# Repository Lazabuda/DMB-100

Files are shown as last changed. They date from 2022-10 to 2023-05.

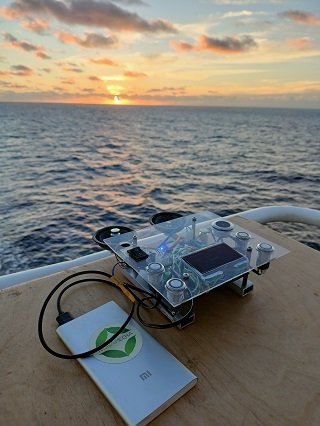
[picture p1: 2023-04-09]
Additional_files/DMB-100.jpg

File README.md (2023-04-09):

# DMB-100
Digital Marine Balances - 100 (max. weight = 100g)

! ! ! ! !
Before PCB mounting:
R43, R44, C24 - do not install (by default). Install if you want to use B channel of ADC HX711.
R25, R33 - do not install if you use internal on-chip oscillator (by default).
R29, R39 - do not install, data rate control, installed R31, R40 means 0: 10Hz (by default); installed R29, R39 means 1: 80Hz.
R20, R23 - do not install if you use internal pull-up's for EPS32 GPIO2 and GPIO4

Something about RTC. You can use many different RTC's in SOIC-8 case and pin-to-pin compatible (if you need time and date on the display). I tried 2 types, one with two domains of power supply (battery and Vcc) and one only with Vcc (it is much cheaper). So, if you use second type with one domain, for example PCF8563, please do steps:
R1 - install 0 Ohm resistor if you use external power supply for RTC (after turning off the device real clock timer progress will be lost). I use this option for first tests. In this case, R2 - do not install.
R2 - install 0 Ohm resistor if you use 2032 battery for RTC (after turning off the device real clock timer progress will be saved). In this case, R1 - do not install.
R5 - not install. This resistor needs to be installed if you use RTC like M41T81

Shortly:

If you use RTC with two power supply domains, like M41T81:
R5, R1 - install 0 Ohm resistors, R2 - do not install

If you use RTC with one power supply domain, like PCF8563:
R2 - install 0 Ohm resistors, R5, R1 - do not install

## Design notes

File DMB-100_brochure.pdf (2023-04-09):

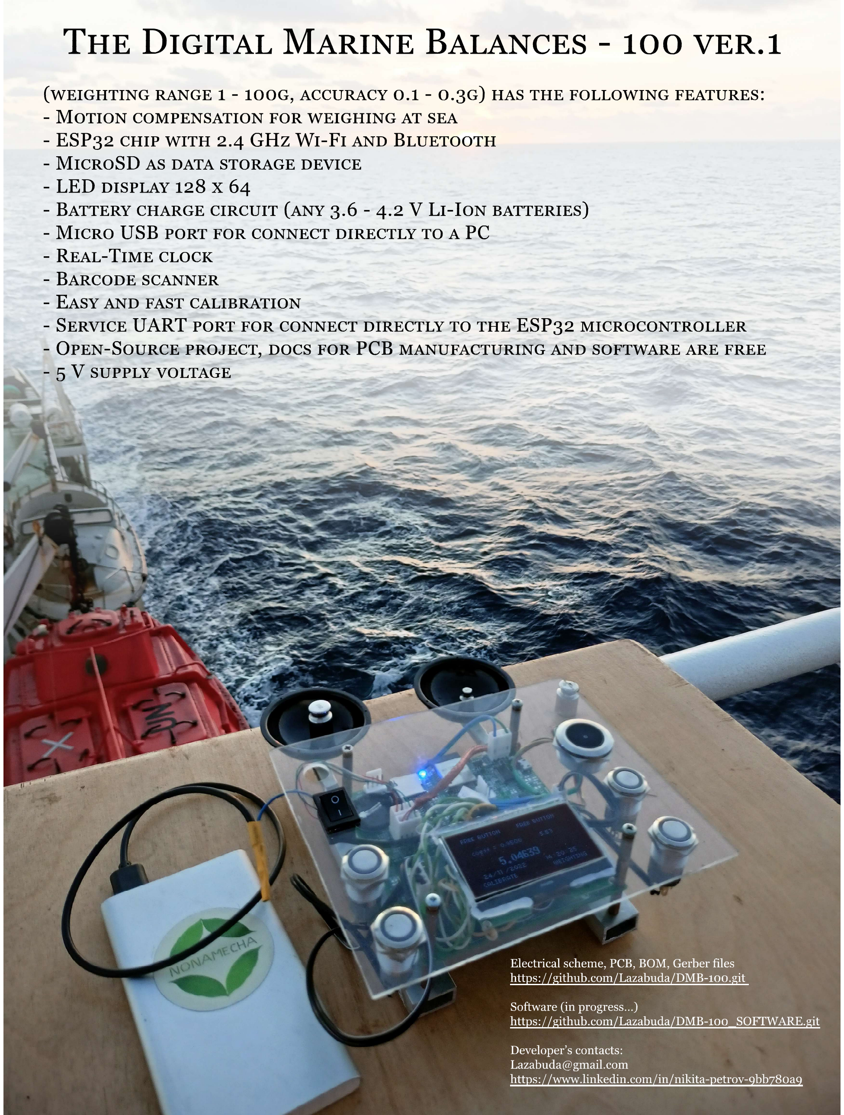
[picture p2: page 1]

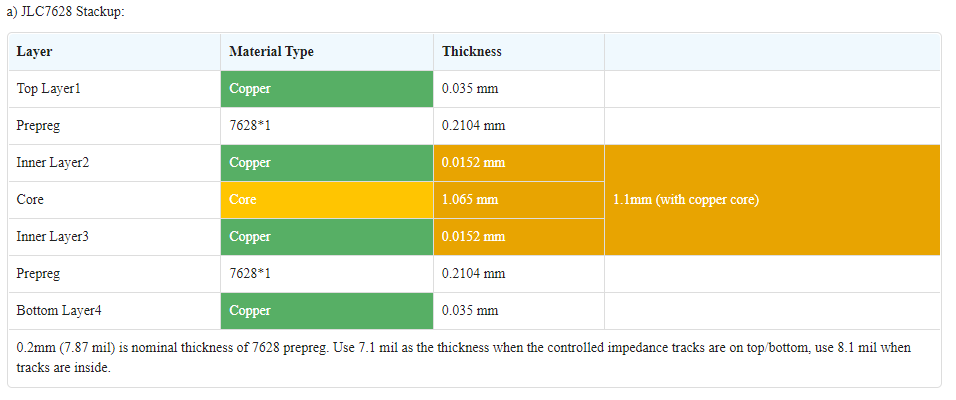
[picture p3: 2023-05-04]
Additional_files/Stackup.png

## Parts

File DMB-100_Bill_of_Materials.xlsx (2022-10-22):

Bill of Material Report (Condensed)
Part | COMP_DEVICE_TYPE | COMP_VALUE | QUANTITY | REFDES | Link
LED 1608 | LED_1608_1608_SMT_LED_LED_1608 | LED_1608 | 5 | VD1;VD2;VD7;VD8;VD10 | https://aliexpress.ru/item/1005003327360045.html?sku_id=12000025230762027
Battery Holder CR2032 | 2032_HOLDER_BAT_CH224_CR2032_2032_HOLDER | 2032_Holder | 1 | BAT1 | https://aliexpress.ru/item/4001240194584.html?sku_id=10000015424733532
Button 3x4x2.5 | BUTTON_4X3_BUTTON_3X4X2_5_BUTTON_4X3 | Button_4x3 | 2 | SW1;SW2 | https://aliexpress.ru/item/4001125532910.html?sku_id=10000014628669783
Button 6x6 | BUTTON_6X6_BUTTON_6X6_BUTTON_6X6 | Button_6x6 | 4 | SW3;SW4;SW5;SW6 | https://aliexpress.ru/item/32725582078.html?sku_id=61197879130
Capacitor 0603 | C_0603_CAP_0603_0.1 UF | 0.1 uF | 22 | C1;C2;C3;C4;C5;C6;C7;C9;C10;C11;C12;C13;C15;C17;C18;C20;C22;C23;C24;C25;C32;C33 | https://aliexpress.ru/item/32966526545.html?sku_id=66569661089
Capacitor 0805 | C_1_CAP_0805_10 UF | 10 uF | 11 | C8;C14;C16;C19;C21;C26;C27;C28;C29;C30;C31 | https://aliexpress.ru/item/32964553793.html
Capacitor 0805 | L_0805_CAP_0805_40 OHM | 40 Ohm | 1 | L1
FUSE 1206 | FUSE_1206_CAP_1206_FUSE_1206 | 500 mA | 2 | FU1;FU2 | https://aliexpress.ru/item/32901034711.html?sku_id=66684643012
Inductance CD54 | CD54_CD54_2.2 UH | 2.2 uH | 1 | L2 | https://aliexpress.ru/item/32886534770.html?sku_id=65669741576
Crystal 32.768 kHz | CRYSTAL_CRYSTAL_CYLINDER_2X6_32.768 KHZ | 32.768 kHz | 1 | Q1 | https://aliexpress.ru/item/4000124720113.html?sku_id=10000000352024848
Diode Shottky | DIODE_SHOTTKY_DIODE_DO-214AC_SS34 | SS34 | 1 | VD6 | https://aliexpress.ru/item/1005002002410774.html?sku_id=12000018375188551
TVS Diode | TVS_DIODE_SC-79_SOD523_DIODE_SOD_523_CESD3V3D5 | CESD3V3D5 | 4 | VD4;VD5;VD11;VD12 | https://aliexpress.ru/item/1005003621698282.html
TVS Diode | TVS_DIODE_SC-79_SOD523_DIODE_SOD_523_CESD5V0D5 | CESD5V0D5 | 1 | VD9 | https://aliexpress.ru/item/1005003638006390.html?sku_id=12000026598964880
Display GMG12864-06D | DISPLAY_DISP_GMG12864-06D_DISPLAY GMG12864 | GMG12864 | 1 | XP1 | https://aliexpress.ru/item/1005001621784395.html?sku_id=12000024622349061
Microcontroller ESP32-D | ESP32-WROOM-32D_2_ESP32-WROOM-32_VER1_ESP32-WROOM-32D | ESP32-WROOM-32D | 1 | DD4 | https://aliexpress.ru/item/32959541446.html
MicroUSB Connector | MICROUSB_CONN_GCT_USB3090-XX-X_MICROUSB_CONN | MicroUsb_conn | 1 | XS1 | https://aliexpress.ru/item/4000774276762.html?sku_id=10000007743655409
Resistor 0603 | R_0603_RES_0603_0 OHM | 0 Ohm | 8 | R1;R2;R5;R27;R31;R35;R40;R50 | https://aliexpress.ru/item/1005001436923851.html?sku_id=12000016109357936
Resistor 0603 | R_0603_RES_0603_10 KOHM | 10 kOhm | 23 | R3;R4;R6;R9;R10;R11;R12;R13;R14;R15;R16;R20;R22;R23;R24;R30;R32;R34;R36;R49;R52;R59;R60 | https://aliexpress.ru/item/1005001793547200.html?sku_id=12000017592827566
Resistor 0603 | R_0603_RES_0603_180 OHM | 180 Ohm | 3 | R7;R8;R17
Resistor 0603 | R_0603_RES_0603_1 KOHM | 1 kOhm | 5 | R18;R19;R46;R47;R56
Resistor 0603 | R_0603_RES_0603_100 OHM | 100 Ohm | 8 | R21;R26;R28;R37;R38;R41;R42;R55
Resistor 0603 | R_0603_RES_0603_NOT INSTALL | Not Install | 6 | R25;R29;R33;R39;R43;R44
Resistor 0603 | R_0603_RES_0603_5 KOHM | 5 kOhm | 1 | R51
Resistor 0603 | R_0603_RES_0603_4.99 KOHM | 4.99 kOhm | 1 | R53
Resistor 0603 | R_0603_RES_0603_1.1 KOHM | 1.1 kOhm | 1 | R54
Resistor 0805 | R_0_RES_0805_0.4 OHM | 0.4 Ohm | 1 | R58
MicroSD Card Holder | TFP09-2-12B_SD_CARD_HOLDER_10-TFP09-2-12B_MICROSD | MicroSD | 1 | XS2 | https://aliexpress.ru/item/32763208642.html?sku_id=62132705394
Real Clock Timer | M41T81_SO8_M41T81 | M41T81 (or analog PCF8523T) | 1 | DD3
Lithium battery charger | TP4056_SO8_TP4056 | TP4056 | 1 | DD7 | https://aliexpress.ru/item/32836023608.html?sku_id=66764109409
Analog Digital Converter | HX711_SOP_16L_HX711 | HX711 | 2 | DD5;DD6 | https://aliexpress.ru/item/4000910231933.html?sku_id=10000010496911197
Bipolar NPN transistor | SS8050_SOT23_SS8050 | SS8050 | 2 | VT1;VT2 | https://aliexpress.ru/item/1005002318967364.html?sku_id=12000020062591621
Bipolar PNP transistor | S8550_SOT23_S8550 | S8550 | 2 | VT3;VT4 | https://aliexpress.ru/item/1005002318967364.html?sku_id=12000020062591621
Diode Array ESD USB | USBLC6-2_SOT95P280X145-6N_USBLC6-2SC6 | USBLC6-2SC6 | 1 | DD1 | https://aliexpress.ru/item/32523780535.html
Battery protection IC | DW01A_SOT95P280X145-6N_DW01A | DW01A | 1 | DD9 | https://aliexpress.ru/item/1005001907754140.html?sku_id=12000018081559151
MOSFETs | 8205_0_SOT95P280X145-6N_FS8205 | FS8205 | 1 | VT7 | https://aliexpress.ru/item/1005001907754140.html?sku_id=12000018081559151
P-Channel MOSFET | P-CH_FET_SOT_23_IRLML6402 | IRLML6402 | 2 | VT5;VT6 | https://www.aliexpress.com/snapshot/0.html?orderId=5018849288338880&productId=32874693069
DC-DC Buck Converter | SY8009AAAC_SOT_23_5LEAD_SY8009AAAC | SY8009AAAC | 1 | DD8 | https://aliexpress.ru/item/32874693069.html?sku_id=65625652318
USB - UART Converter | FT232RL_0_SSOP28-065-102X52MM_FT232RL | FT232RL | 1 | DD2 | https://aliexpress.ru/item/4000014754902.html?sku_id=10000000035995956
Connector WF-2 | WF-2_WF-2_WF-2 | WF-2 | 5 | XP2;XP4;XP7;XP10;XP13 | https://aliexpress.ru/item/32865507705.html?sku_id=65370747313
Connector WF-3 | WF-3_WF-3_WF-3 | WF-3 | 1 | XP9
Connector WF-4 | WF-4_WF-4_WF-4 | WF-4 | 7 | XP3;XP5;XP6;XP8;XP11;XP12;XP14
Barcode Scanner GM60 UART |  |  | 1 |  | https://aliexpress.ru/item/4001314293705.html?gatewayAdapt=glo2rus&sku_id=10000015695395320
Load Cell 100g |  |  | 2 |  | https://aliexpress.ru/item/33060350901.html?sku_id=67589624595

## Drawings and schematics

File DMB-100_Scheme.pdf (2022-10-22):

# Vbus

D- | 2

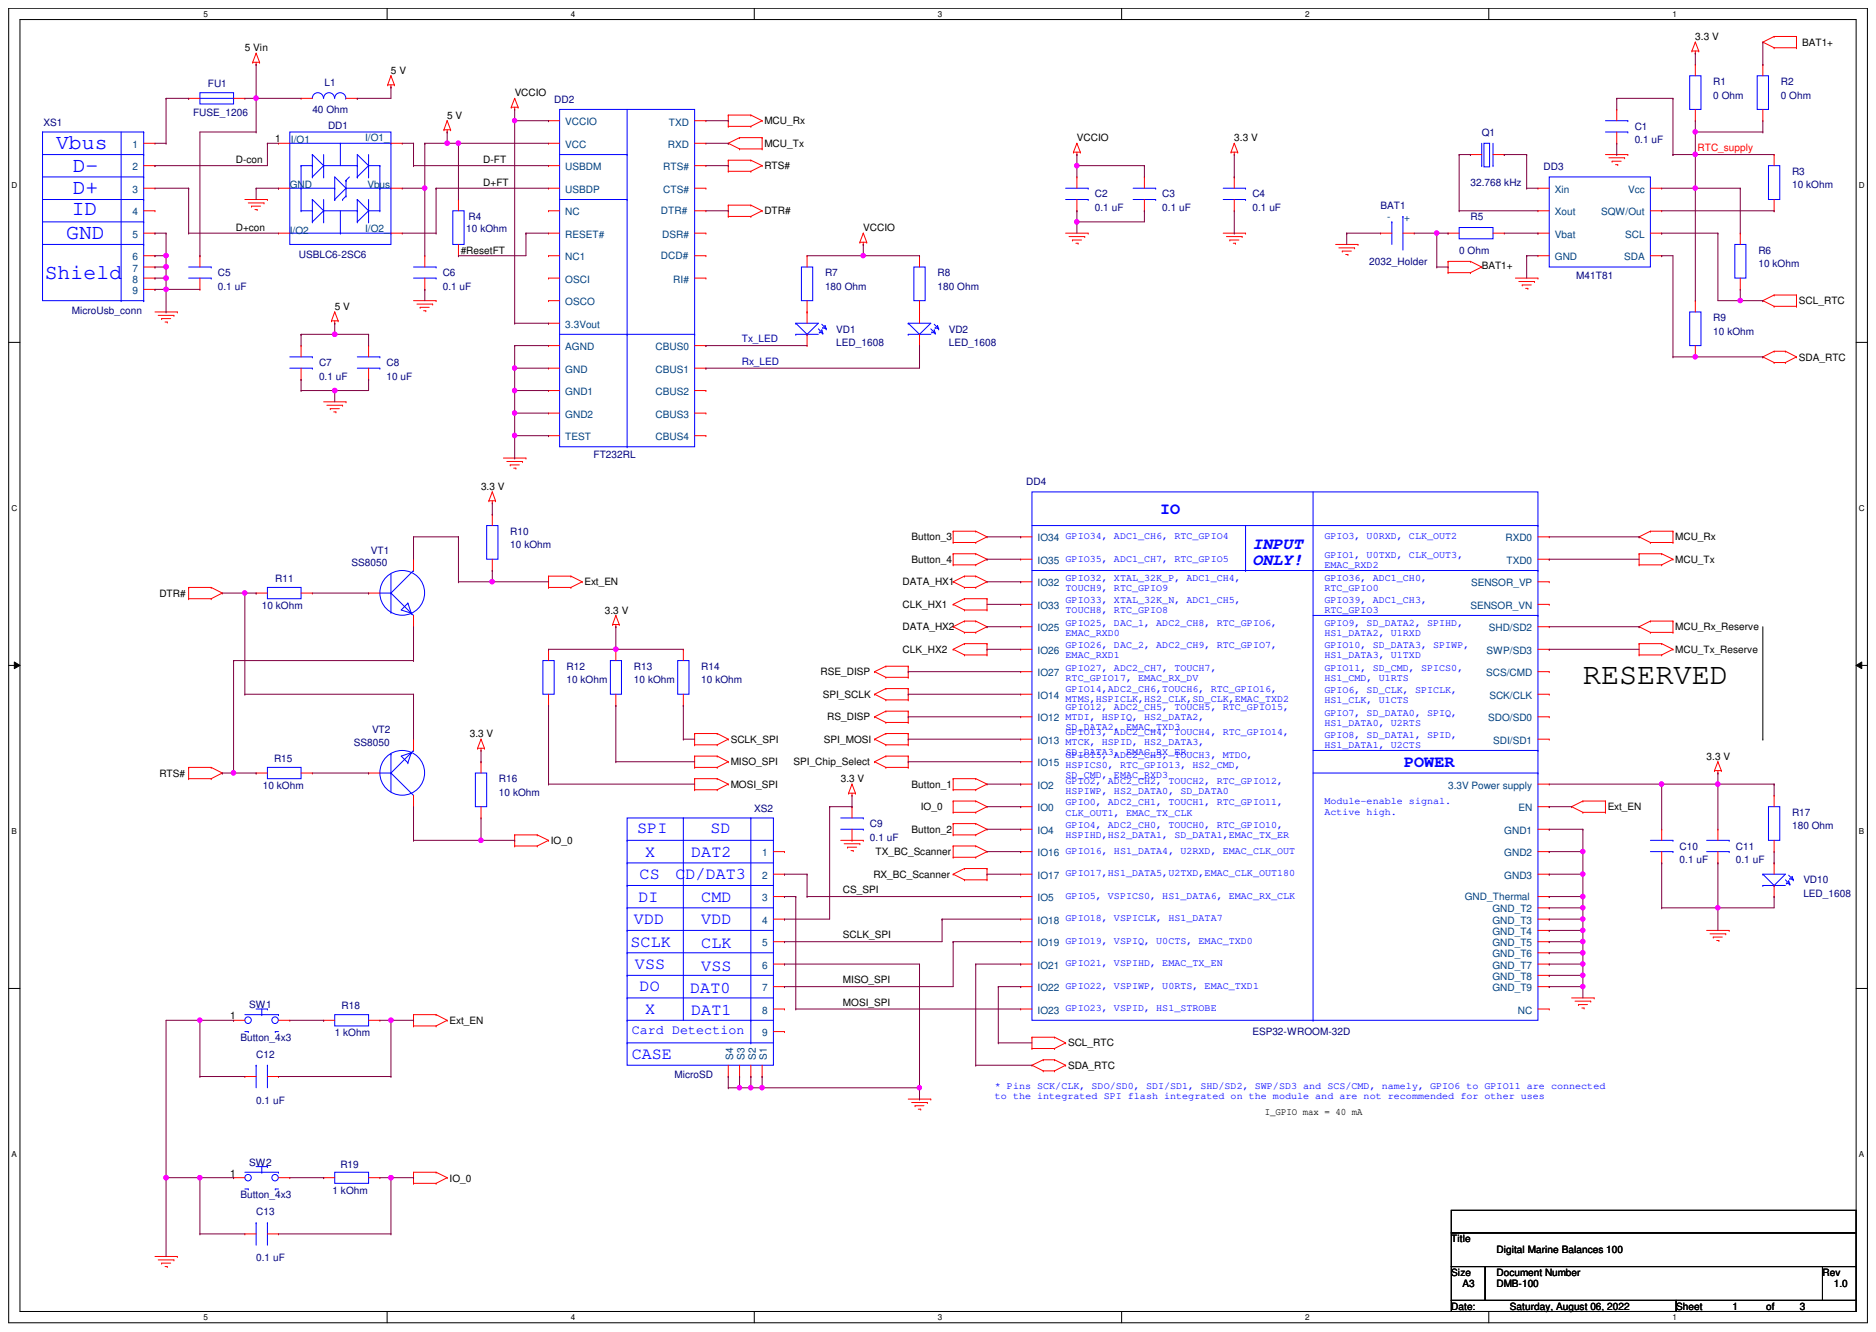
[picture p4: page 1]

D+ | 3
ID | 4
GND | 5

Shield | 6 7 8 9

* Pins SCK/CLK, SDO/SD0, SDI/SD1, SHD/SD2, SWP/SD3 and SCS/CMD, namely, GPIO6 to GPIO11 are connected
to the integrated SPI flash integrated on the module and are not recommended for other uses

# TO - DISPLAY

### GND

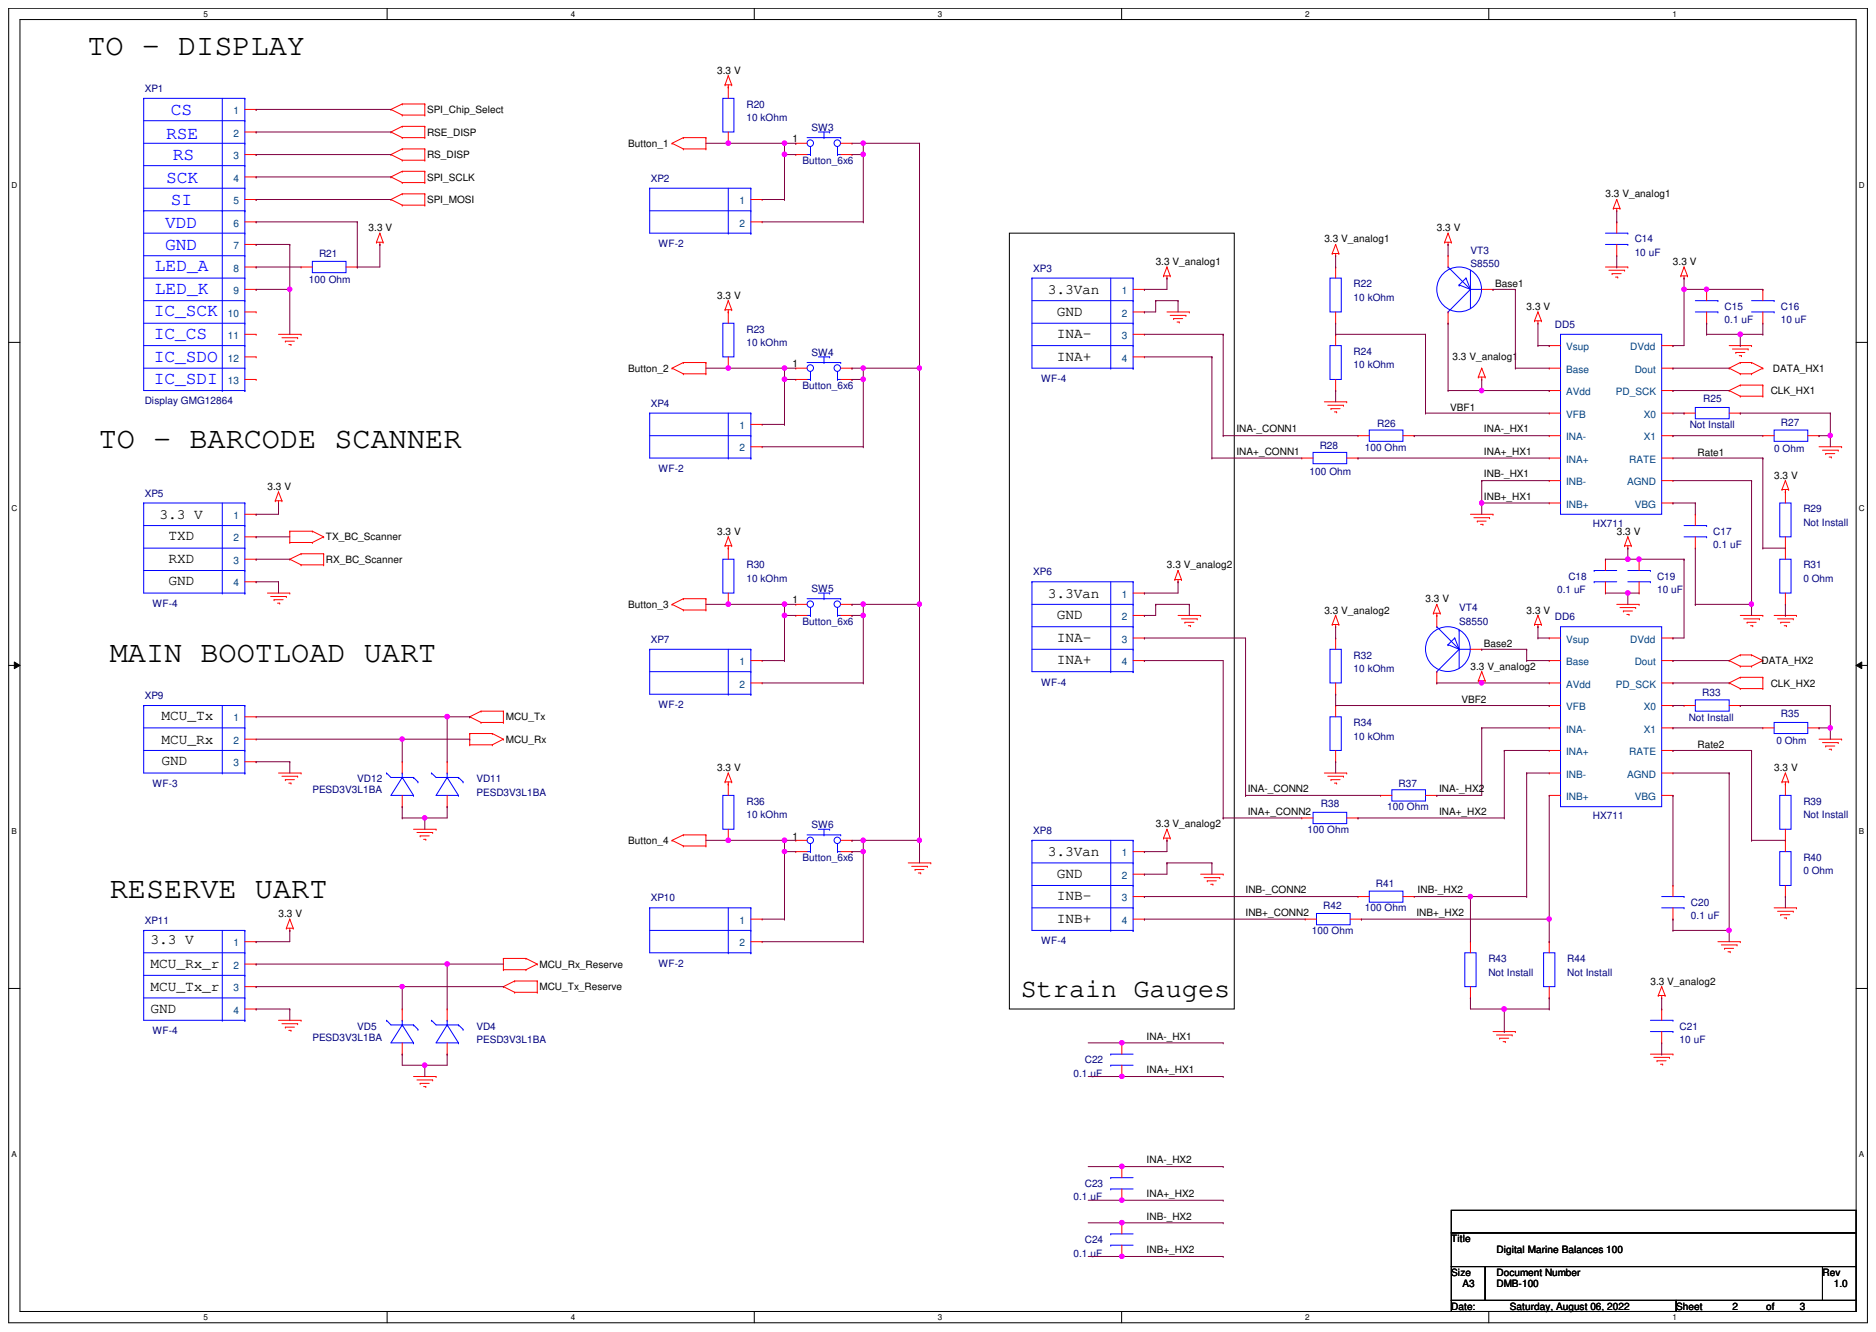
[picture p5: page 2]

CS | 1
RSE | 2
RS | 3
SCK | 4

GND | 7
LED_A | 8

3.3 V | 1
TXD | 2
RXD | 3
GND | 4

3.3Van | 1
GND | 2
INA- | 3

MCU_Tx | 1
MCU_Rx | 2
GND | 3

INB- | 3

MCU_Rx_r | 2
MCU_Tx_r | 3

## BAT+

## BAT-

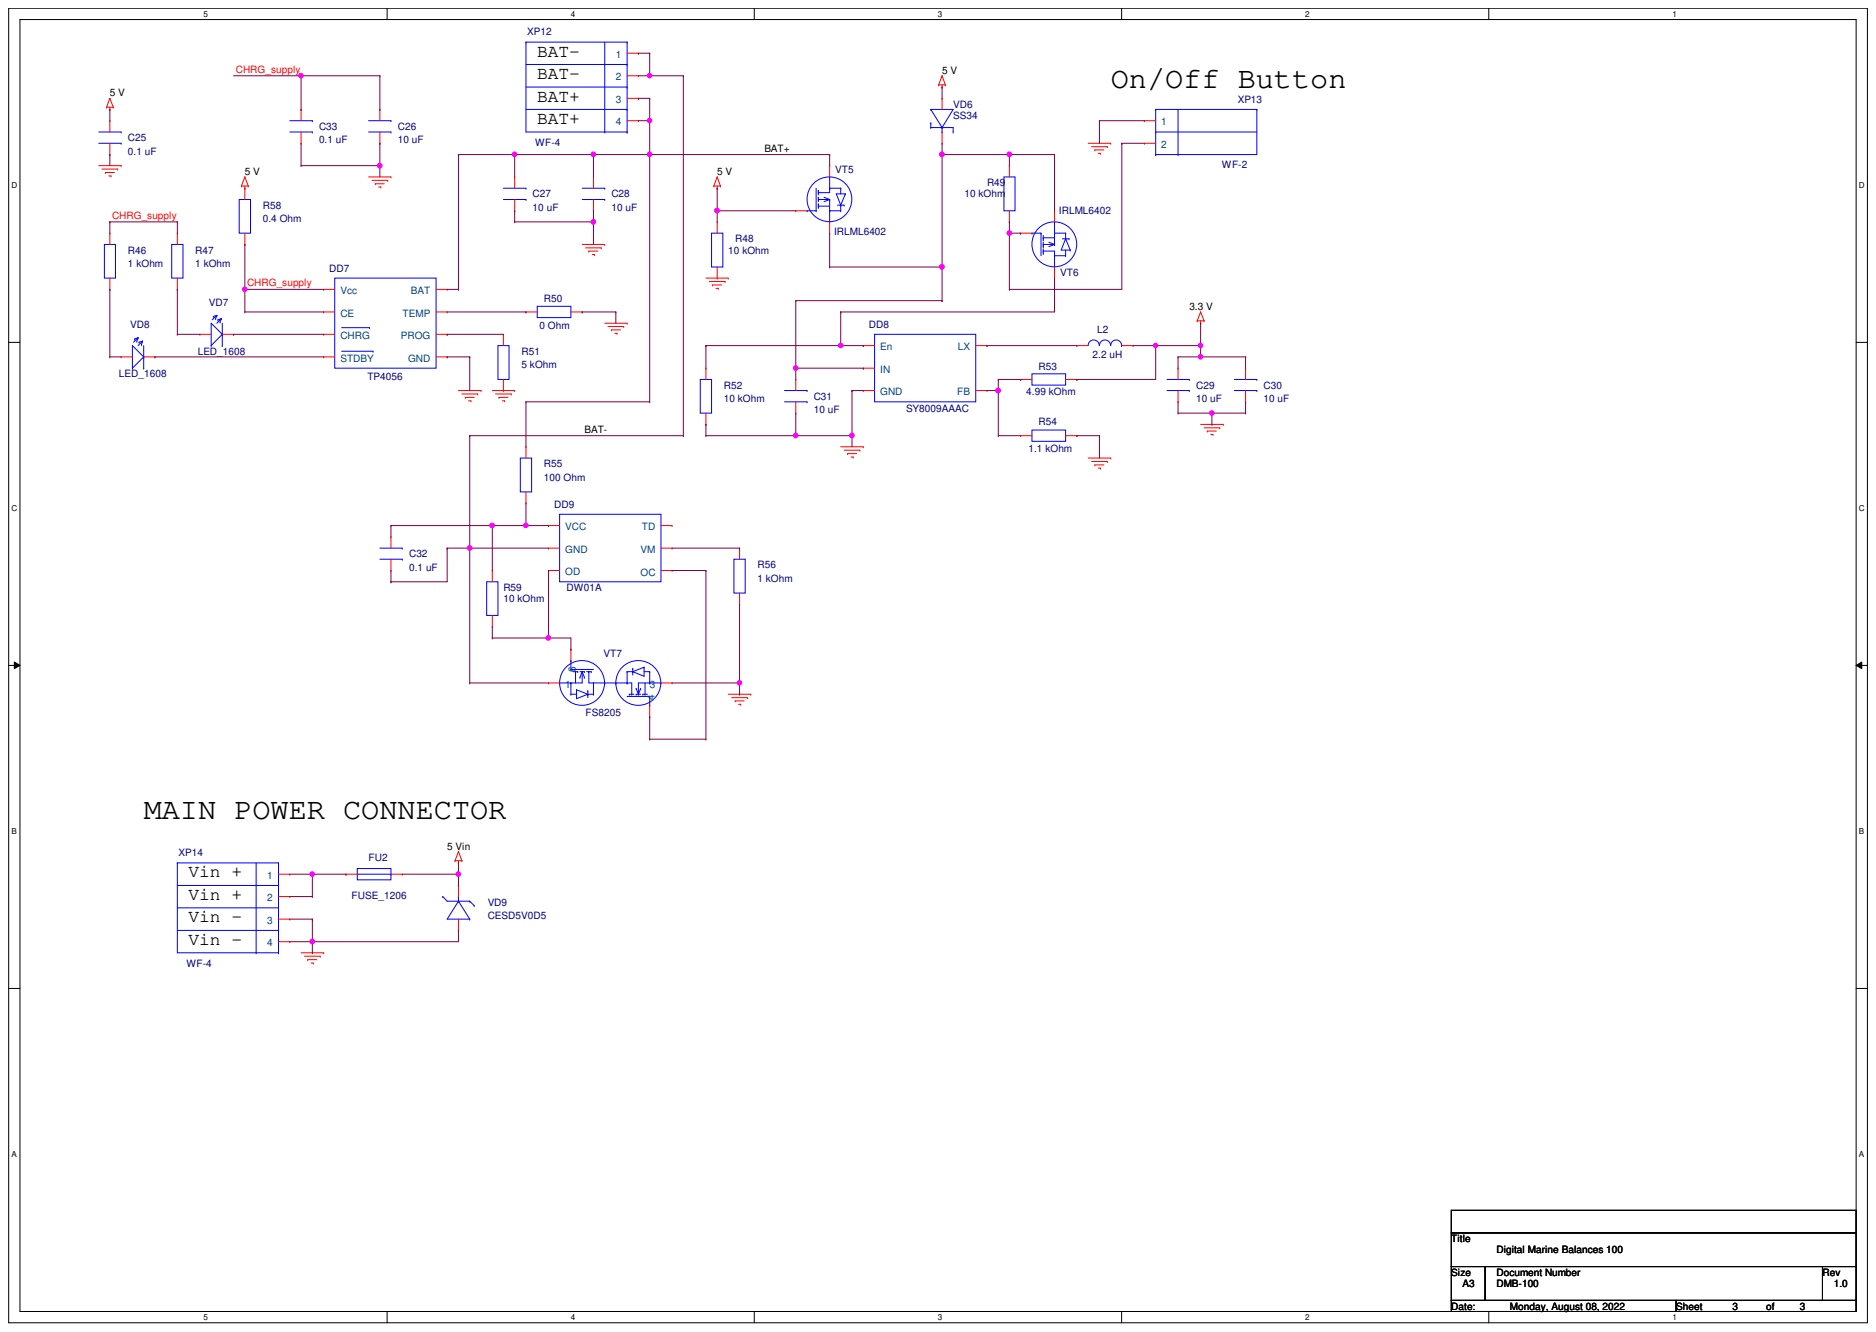
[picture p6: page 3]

BAT-
BAT+ | 3

Vin + | 1
Vin + | 2
Vin - | 3
Vin - | 4

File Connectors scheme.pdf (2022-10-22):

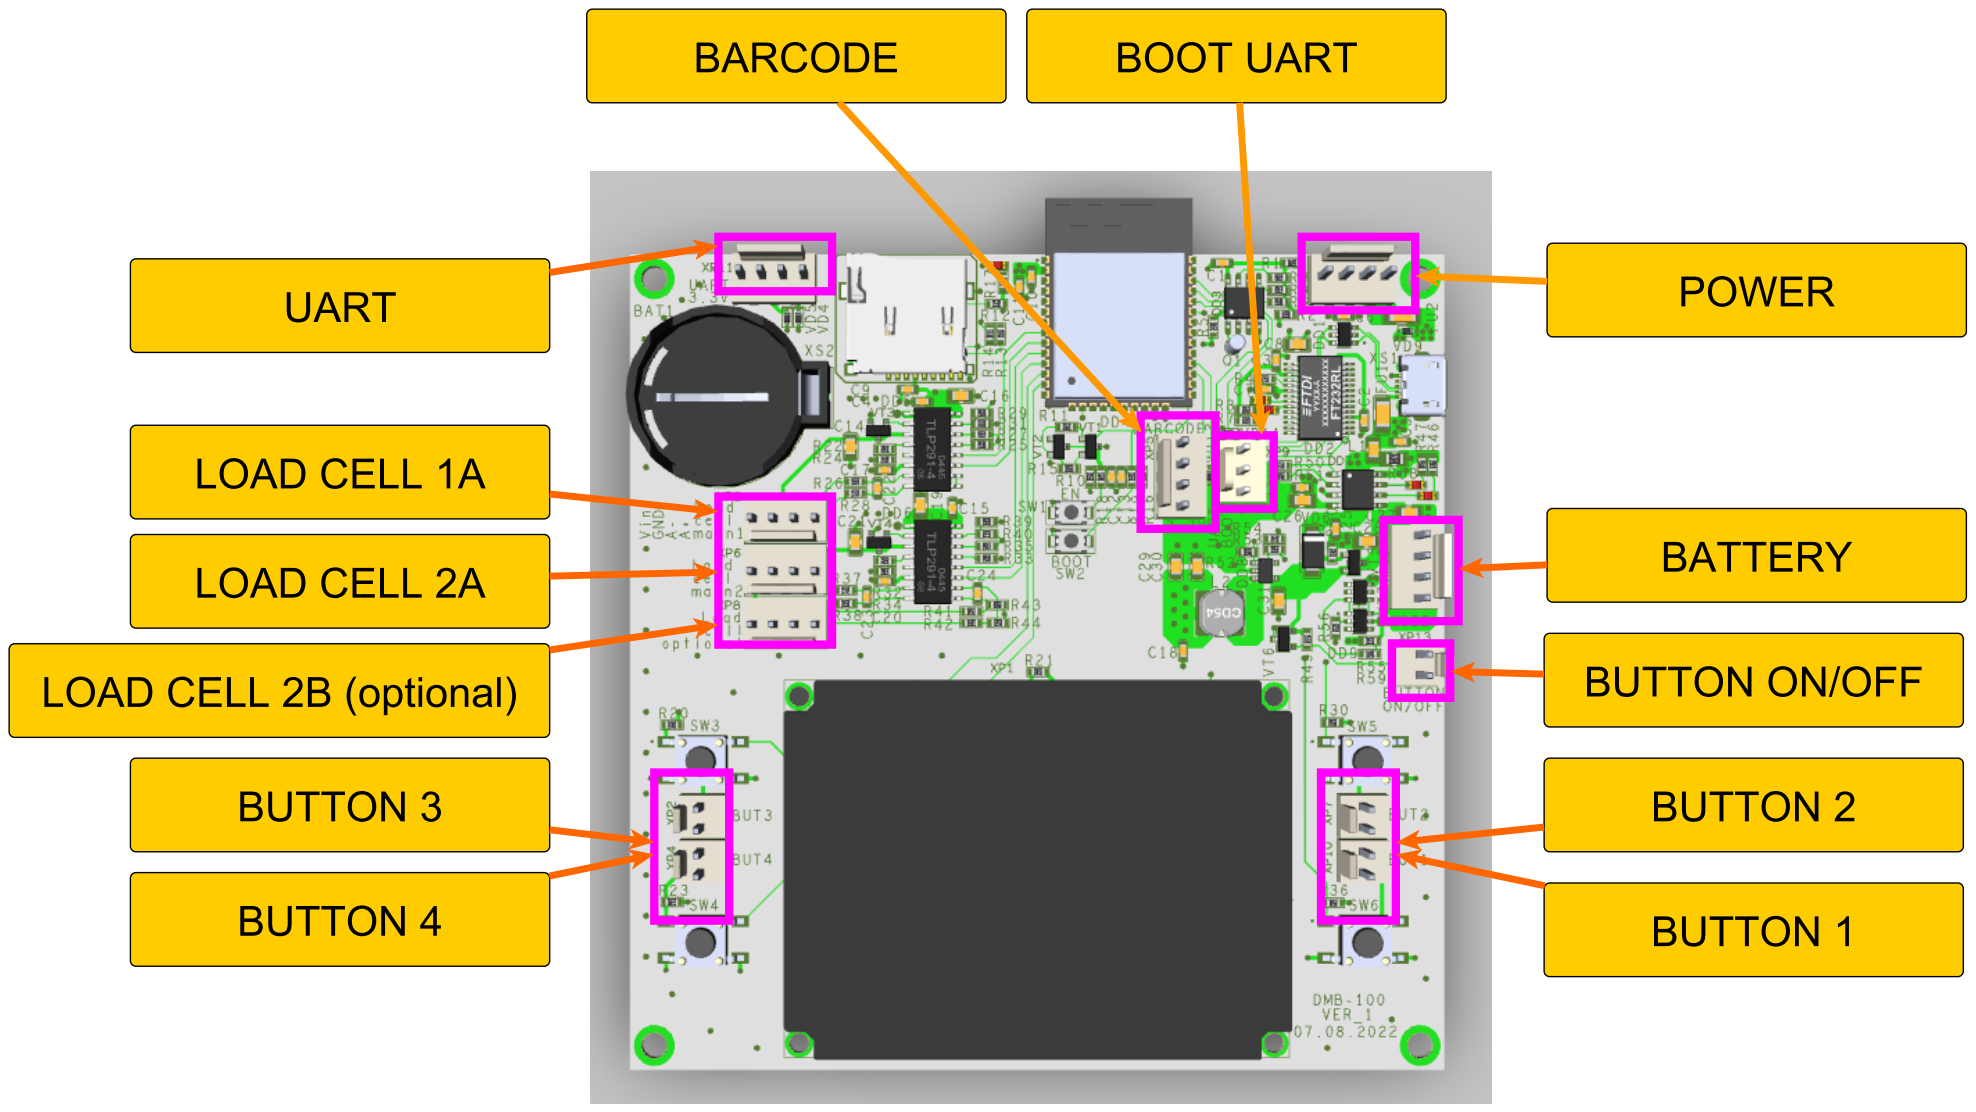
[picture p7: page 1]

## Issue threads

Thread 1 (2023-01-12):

Corrections to the next revision (DMB-100 Ver.2)

Lazabuda, 2023-01-12:
1. Connect 4 mounting holes to the Ground
2. Add one more pin to the Load Cell connectors
3. Crystal padstack must be wider

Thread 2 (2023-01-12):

Orientation and temperature logger

Lazabuda, 2023-01-12:
Connect through UART to the ESP32 and write in the log more information about scales orientation ant current temperature.

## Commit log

2022-10-22 Electrical scheme, BOM, .brd file of Digital Marine Balances - 100
    [DMB-100_Bill_of_Materials.xlsx, SHIP_SCALES.DSN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]
2022-10-22 Added connectors_scheme.pdf
2022-11-25 Update README.md
    Added description of DNI resistors
2023-05-04 Added stackup screenshot
    [SHIP_SCALES.DSN]
